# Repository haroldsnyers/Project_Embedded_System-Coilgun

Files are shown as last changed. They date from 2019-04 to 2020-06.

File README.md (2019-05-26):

# Project_Embedded_System-Coilgun
## Introduction
This Coilgun project is a project under the car of the ECAM.

The purpose of this project was to make a school laboratory experience which could be actionned remotely from the student's home. It was demanded to use atleast 2 of 3 following modules: 
- arduino
- Beagle Bone Black
- PIC

We choose the arduino and the BBB. The arduino will be connected the coilgun electronic circuit, to a proximity sensor and a bouton. The type of connection we chooses to connect the arduino to the BBB is through uart and finally by MQTT we choose to connect the BBB with the Node-RED interface. 

## SETUP
### arduino
One of the things we wanted to measure was the speed of the projectile. To do that we took a proximity sensor and a push button. In the arduino code, a first variable is activated when the projectile passes the sensor and a counter starts, then only if that variable is activated, it listens to the pin connected to the button and when pushed (projectile has reached target), counter stops and this time the value is send through uart to the BBB. The pins of the arduino connected to the buttons can be read in the code, same as the RX and TX port for the uart connection, pin 10 and 11 respectively.
When everything is setup upload the arduino file into your arduino board.
### Beagle Bone black
The arduino is connected via uart to the UART1 of the BBB, p9.24 and p9.26, TX and RX respectively. One more cable is needed to connect the arduino and BBB on the same GND. 
When everything is setup, you will need to upload the files read and write into the BBB (easy way : use filezila, connect `sftp://<IpAdress>`, username and password).
Open then 2 bash terminals and connect to your BBB on each of them. When connected on each of those terminals to the BBB, enter the following commands
```
config-pin p9.24 uart
config-pin p9.26 uart
stty -F /dev/ttyO1 sane
```
After that just run the two python scripts running the following commands : 
```
python readuart_Arduin-BBB-Dash.py
```
and 
```
python writeUart_Dash-BBB-Arduino.py
```
The readuart script retrieves data send by the arduino in the form of a string, this string is then decomposed by means of a letter describing which data it is and in function of that publish the value in right topic generated by the Node-RED interface. 
The write uart retrieves data from a topic of the Node-RED interface he is subscribed to and send this data through uart to the arduino board.
### Node-RED
You need to start from your command prompt node-red and go to the following pair `<IP:port>` in your browser `localhost:1880`
After that you can download the flow for the Node-RED dashboard in JSON form. This can be done by clicking on the dropdown in the upper right corner and choosing import from clipboard. After that you can go to the dashboard by going to `http://localhost:1880/ui`.
You should arrive to a dashboard looking like this : 

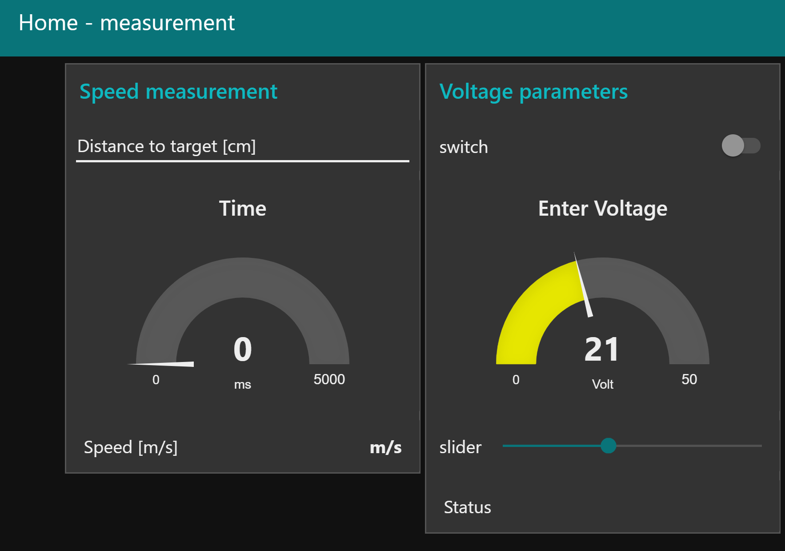
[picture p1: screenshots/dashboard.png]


The Speed bloc works with the following nodes :
- **_input text node_** to input the distance between the coilgun and the target
- **_gauge node_** to display the time it took to reach the target
- **_text node_** to display the speed of the projectile
- **_mqtt IN node_** to subscribe to the topic sensor/time

The speed will only be displayed if the distance has been given and the time has been pusblished. This can be done with the following function :

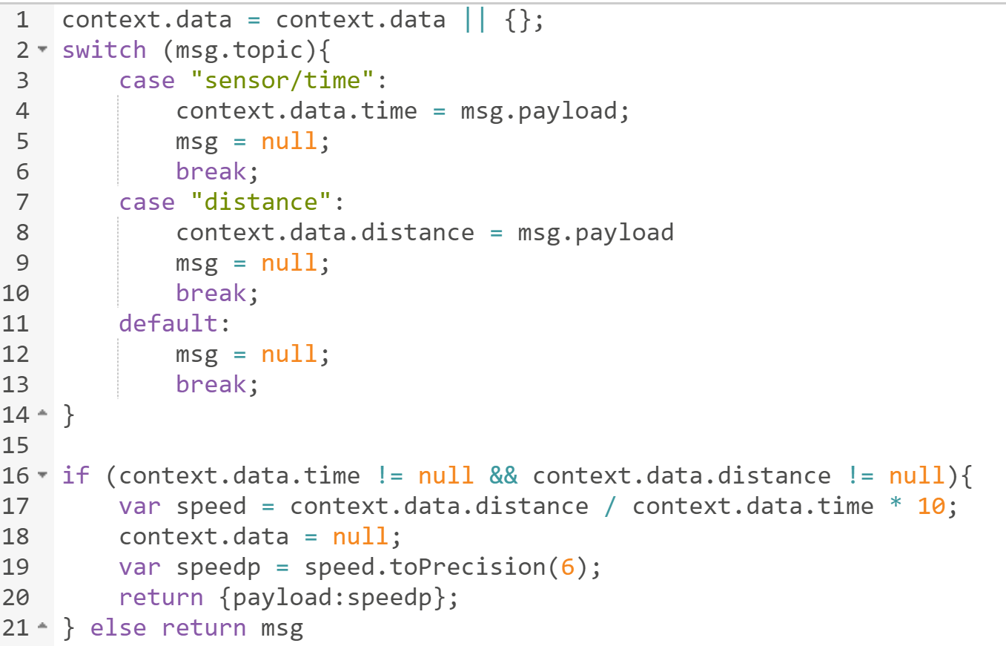
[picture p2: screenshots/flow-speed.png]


The voltage bloc works with the following nodes :
- **_switch node_** to enable the launch 
- **_gauge node_** to display the voltage selected with the slider
- **_slider node_** to select to voltage to launch the projectile
- **_text node_** to display the status of the launch
- **_mqtt IN node_** to subscribe to the topic sensor/conf
- **_mqtt OUT node_** to publish to the topic sensor/test

The voltage will be send to the arduino if the switch is ON and the slider has been moved after that with the following questions :

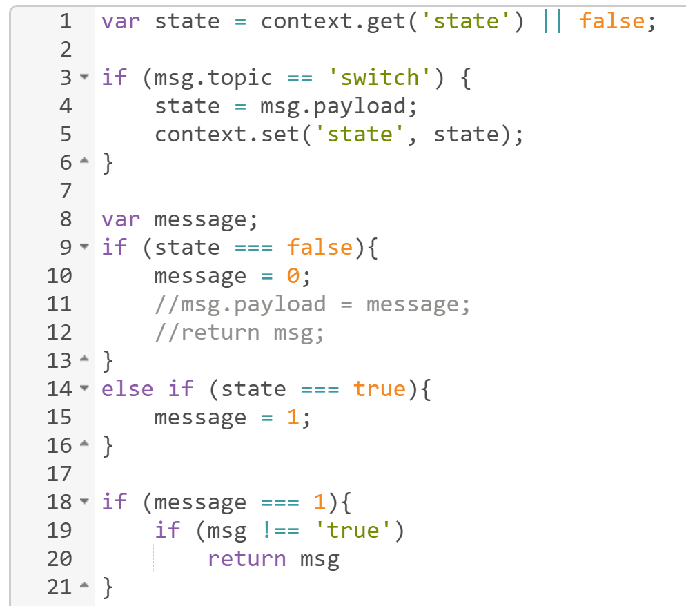
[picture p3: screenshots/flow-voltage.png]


The status mqtt IN sends a status message about the launch if the voltage has been send properly to the arduino.

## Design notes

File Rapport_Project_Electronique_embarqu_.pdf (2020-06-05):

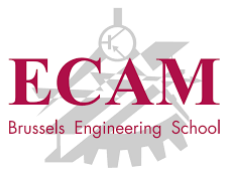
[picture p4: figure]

Projet Electronique Embarqué

# Canon de Gauss

Auteurs :
Harold Snyers 16243
Bernard Tourneur 16148
Christos Bournousouzis 16219

Professeurs :
Mr. Sébastien Combefis ´

Mr. Cédric Marchand

Un canon électromagnétique contrôlé à distance

depuis un tableau de bord

Année académique 2018-2019

## Contents

Contents | i
1 Canon de Gauss | 1
A Appendix | 8

Page - i

## Canon de Gauss

## 1.1 Introduction

L’objectif du projet est d’implémenter une expérience de laboratoire de niveau secondaire,

contrôlable à distance depuis un ordinateur. L’utilisateur doit pouvoir déclencher l’expérience,

et récupérer les éventuelles données à collecter, le tout depuis un panneau de bord (ou

”dashboard”) sur son ordinateur.

Nous avons choisi comme sujet d’expérience l’électromagnétisme et le rendement énergétique.

L’expérience consiste à mesurer l’énergie cinétique d’un projectile lancé par un canon de

Gauss (ou canon électromagnétique), à la comparer avec l’énergie électrique consommée

par le système, pour en déterminer le rendement énergétique.

## 1.2 Développement électronique

### 1.2.1 Fonctionnement du canon

Un canon de Gauss consiste en un bobinage cylindrique creux, le projectile placé en

son centre, auquel on applique un pic de courant important. Ce dernier va générer une

variation de flux magnétique, créant une force magnétomotrice maximale au centre de

la bobine et lançant ainsi le projectile. Plusieurs facteurs affectent la valeur de la force

magnétomotrice générée; la bobine en elle même, son impédance, le nombre de tours de

fils, etc; mais également le courant électrique qui la traverse, et la quantité d’énergie

disponible.

Ainsi, pour pouvoir libérer un maximum de courant le plus vite possible, nous avons choisi

d’accumuler les charges dans des condensateurs (à capacité relativement grande).

Pour charger les condensateurs (placés parallèlement à la bobine), le circuit doit être ou-

vert derrière ceux-ci, et ils doivent être mis sous tension. Une fois les condensateurs pleins

(lorsque leur tension est plus ou moins égale à la tension de charge), on peut fermer le

circuit (à l’aide d’un relais électromécanique); la bobine se comportera alors comme un

court-circuit (ou une résistance très faible) et les condensateurs se déchargeront brusque-

ment, provoquant un pic de courant important dans la bobine.

Canon de Gauss

Il est important que le relais ne soit fermé qu’un bref instant, pour que l’impulsion

soit momentanée; si elle dure trop longtemps, la force magnétomotrice provoquera une

décélération du projectile.

### 1.2.2 Schémas

Tous les schémas du système se trouvent en annexe; les références vers ceux-ci pointent

donc vers la fin de ce document.

Voici le détail des composants du schéma général (Figure A.1):

- Condensateur x 6
- Résistance x 6
- Diode x 1
- Relais x 1
- Bobine x 1

La source de tension est contrôlable à distance; elle n’a pas été intégrée dans notre pro-

totype mais est nécessaire pour un contrôle complet du système à distance.

Analysons le schéma général par bloc fonctionnel.

a Charge des condensateurs

(Figure A.2)

Dans ce bloc, la résistance sert à limiter le courant de charge des condensateurs. Les condensateurs vont donc se charger jusqu’à la tension d’alimentation du système¹
, moins

la tension présente sur la diode (environ 0.7 V). Cette dernière sert à empêcher la décharge

des condensateurs lorsque la source est éteinte; sans elle, les condensateurs pourraient se

décharger au travers de la résistance.

b Décharge des condensateurs

(Figure A.3)

Pour fermer le circuit, un relais électromécanique est placé entre les condensateurs et la

bobine, faisant office d’interrupteur. L’entrée du relais, (qui commande l’électro-aimant

1Dans notre prototype, 50V

Canon de Gauss

activant la commutation) est connectée à une sortie de l’Arduino. Lorsque l’Arduino

envoie 5V, le relais est passant et le projectile lancé.

Comme mentionné précédemment, il faut que le relais soit fermé pendant un temps rela-

tivement court. Nous avons déterminé par essai-erreur que, sous 50V, un temps ”passant”

de 150 ms suffit.

Pour éviter que les condensateurs continuent de se charger lors du tir, nous avons choisi

d’éteindre la source de courant avant la mise à feu. Nous avons en effet constaté une

légère augmentation de performances dans ces circonstances. L’hypothèse retenue est que

le courant entrant dans les condensateurs limite le courant sortant, diminuant ainsi la

valeur totale de courant dans la bobine.

Pour avoir un grand gain de courant, nous avons décidés de mettre nos condensateurs en

parallèle.

Si nous faisons le calcul :
Avec Rtot ' 30 ohm, pour un condensateur on a : I = 50
30 = 1.67A

Itot = I*6 ' 10A, on aurait donc +/- 10A qui passerait dans notre bobine pour une

tension de 50V.

c Mesure de tension

(Figure A.4)

Pour mesurer la tension sur les condensateurs nous utilisons un diviseur de tension de rap-

port 10 (valeur expérimentale = 9.1314) car l’ADC de l’Arduino ne convertit pas une ten-

sion supérieur à 5V (si nous prenons la référence interne de l’Arduino bien évidemment).

Nous avons utilisé des résistances très grandes pour éviter d’avoir trop de perte de courant.

Nous prenons la mesure entre R2 et R3 et nous la connectons à une pin analogique de

l’Arduino.

d Mesure de courant

(Figure A.5)

Nous utilisons une résistance de puissance de 1 ohm comme résistance de shunt, pour

mesurer le courant passant dans la bobine.

U = R * I → U = 1 * I → U = I

La valeur de courant est donc directement donnée par la tension lue. Pour éviter d’endommager

l’ADC de l’Arduino en cas de pic de courant important, nous utilisons un diviseur de ten-

sion de rapport 3 (valeur expérimentale = 2.241).

Canon de Gauss

e Capteur de vitesse

(Figure A.6)

Pour déterminer la vitesse du projectile (qui sera utilisée pour trouver son énergie cinétique via E=(m∗v

2
2

), on procède en deux étapes : dans un premier temps, l’utilisateur entre la

distance entre le canon et la cible; ensuite, après le tir, le système détermine le temps de

parcours du projectile.

Pour calculer le temps de parcours, on place sous l’extrémité du canon un capteur in-

frarouge (connecté à l’Arduino), détectant le passage du projectile. L’instant de passage

du projectile est enregistré dans l’Arduino. Il s’agit d’un capteur digital, qui envoie un 1

logique lorsqu’il détecte un passage. Sur la cible est placé un bouton poussoir, connecté

également à l’Arduino. Lorsque le projectile atteint cette cible, il enfonce le bouton pous-

soir, qui envoie alors un 1 logique à l’Arduino.

Une simple différence tdépart - tarrivée permet de trouver le temps de parcours. La

vitesse sera calculée directement dans le dashboard.

### 1.2.3 Améliorations possibles

La diode pourrait être remplacée par un relais commandé via l’Arduino. Dans ce cas,

nous n’aurions plus besoin d’une source commandée mais d’une simple source qui restera

constamment branchée, l’Arduino contrôlant quand ouvrir le circuit et donc quand arrêter

la charge des condensateurs.

Pour optimiser la puissance du canon, il est recommandé de prendre une bobine avec un

noyau ferromagnétique.

Au niveau de la lecture de la tension sur les condensateurs et de la lecture du courant,

plusieurs choix s’offrent à nous; soit des résistances beaucoup plus précises pour le diviseur,

soit utiliser un ADC externe permettant de lire des tensions plus importantes.

Pour le capteur de vitesse, il faudrait remplacer le bouton poussoir. En effet, l’énergie

du projectile est insuffisante pour l’enfoncer. Ce problème pourrait être résolu soit en

utilisant un bouton plus sensible, soit en appliquant plus de tensions à la bobine, et donc

en fournissant plus d’énergie au projectile.

Le capteur de mouvements pose également problème; il ne détecte pas systématiquement

le passage du projectile. Idéalement, il faudrait mieux le positionner, en le fixant au

canon, et en s’assurant que le projectile passe systématiquement au dessus du capteur.

Canon de Gauss

## 1.3 Développement télématique

### 1.3.1 Choix des protocoles

Nous avons choisi le protocole UART pour la communication BBB-Arduino car :

- La librairie Serial Arduino implémente déjà ce protocole, est simple à utiliser et

fiable.

- La BBB et l’Arduino sont les seuls présents sur le bus; il n’y a aucun esclave donc

pas de relation maitre-esclave ni d’adressage nécessaire.

- La communication se fait dans les deux sens systématiquement, quand la BBB envoie

un msg elle doit recevoir une réponse, il est donc intéressant d’utiliser un protocole

full duplex.

Aucun protocole n’est utilisé pour les capteurs, qui envoient de simple signaux logiques

si nécessaire.

### 1.3.2 Configuration Arduino

Le code est disponible dans l’appendice section A.2.1.

Comme précisé, nous implémentons la communication UART à l’aide de la librairie Serial;

nous commençons par créer le bus mySerial et choisissons les pins utilisées.

S’en suit l’initialisation des variables et des pins. Dans le void setup, le bus Serial est

démarré et les pins les pins uart ou autres composants sont configurées.

Dans le void loop, il y a deux parties. Une partie permet de lire ce que l’Arduino reçoit

sur le Serial. Ici, elle attend de recevoir la valeur de la tension à appliquer afin d’activer

le premier transistor de puissance qui laissera donc passer la tension requise et donc de

charger les capacités. Quand le tension est atteinte, le transistor est coupé. L’autre

transistor est alors activé afin d’envoyer le courant sur la bobine.

Le bloc suivant permet de vérifier que la valeur de tension a bien été envoyée.

Enfin, le temps de parcours est calculé en testant d’abord si le projectile a survolé le

capteur de mouvement, ensuite s’il a enfoncé le bouton; à chaque évènement, il enregistre

le temps de passage, et fini par calculer une différence de temps qu’il peut envoyer à la

BBB.

Canon de Gauss

### 1.3.3 Configuration Beagle Bone Black

Pour lancer l’écoute et l’envoi des données entre la BeagleBone et l’Arduino nous avons

2 programmes, un pour l’écoute (readuart Arduin-BBB-Dash.py) et l’autre pour l’envoi

(writeUart Dash-BBB-Arduino.py). Ces 2 programmes vont permettre non seulement à

la BeagleBone de communiquer avec l’Arduino en UART mais également de communiquer

avec le dashboard via MQTT. Nous avons choisi d’écrire ces programmes en python pour ses avantages de clarté et de lisibilité, et parce que la librairie UART utilisée²
intègre des

fonctions C dans le code python, permettant des performances quasi équivalentes à un

code C, pour la communication.

La première chose à faire est de choisir sur quel port UART se connecter, puis le port de

la connexion MQTT, généralement le port 1883.

Les codes sont disponibles dans l’Appendice section A.2.2.

readuart Arduin-BBB-Dash.py

La BeagleBone attend de recevoir quelque chose de l’arduino et enregistre le contenu reçu

s’il y a des données disponible sur le Serial. Ensuite, il déchiffre les données reçues (chaque

information transmise en UART est identifiée par un caractère, permettant à la BBB de

différencier les valeurs reçues de l’Arduino) et en fonction, publier les valeurs obtenues

sur les topics respectifs. Les données reprises sur le Serial de l’Arduino sont en format

string, donc avant de les publier, les données numériques sont converties en int.

writeUart Dash-BBB-Arduino.py

La BBB attend de recevoir une valeur sur le topic sur lequel elle est abonnée et, lorsqu’une

valeur est disponible, envoie cette même valeur sur le Serial de l’Arduino.

### 1.3.4 Configuration DashBoard

Le dashboard présente l’interface utilisateur (Figure A.7). Il a été configuré à l’aide de

l’outil de programmation Node-RED.

Les données entrantes arrivent par 4 topics MQTT : sensor/time, sensor/current, sensor/-

voltageIn et sensor/conf. Le dashboard est composé de plusieurs parties. Il y a 4 com-

partiment, le premier affiche la mesure de la vitesse, le deuxième s’occupe d’envoyer les

paramètre de tension et affiche la tension réellement appliquée. Les 2 derniers sont respon-

sables d’afficher la mesure de courant et les la calcul de l’énergie cinétique et électrique.

2Adafruit BBIO.UART

Canon de Gauss

Le flux du dashboard se divise en deux parties.

La première partie (figure A.8), est composée d’un slider pour choisir la tension à appli-

quer, d’une gauge qui affiche la tension choisie et finalement un switch qui va permettre

d’activer l’envoi de la tension sur le topic sensor/voltage. Le topic entrant sensor/conf

affiche le status de l’envoi de la tension dans bloc texte.

La deuxième partie (figure A.9), est composée de 3 données entrantes par MQTT. Chacune

des valeurs de ces topics est affichée dans leur bloc texte respectif. Ensuite un bloc

”inputtext” permettra à l’utilisateur d’entrer la distance entre le canon et la cible.

Une fonction est chargée de récupérer les valeurs des différents topic MQTT et la distance

entrée, d’envoyer les valeurs de tension et de courant aux afficheurs respectifs, puis de

calculer les valeurs de vitesse, énergie cinétique et électrique, et enfin le rendement. Le

code est disponible dans l’annexe à la section A.2.3.

En pratique, la tension choisie n’influence pas le système dans notre prototype; la tension

de charge des condensateurs sera toujours égale à la tension d’alimentation, puisque nous

ne disposons pas d’alimentation contrôlable électriquement, et n’avons pas implémenté

le relais de contrôle mentionné plus tôt. L’envoi de la tension aura donc pour seul

conséquence la mise à feu immédiate du canon de Gauss.

## 1.4 Conclusion

Le projet est fonctionnel, bien qu’il ne soit qu’un prototype et qu’il y ait encore beau-

coup de place pour des améliorations. Certaines parties de l’expérience doivent encore

être simulées manuellement (il faut appuyer sur le bouton poussoir, cfr section 1.2.3:

améliorations possibles).

Le projet a été très instructif à plusieurs niveaux; comme premier projet où nous avons

conçu et designé un circuit électronique, nous avons beaucoup appris de nos erreurs et

développé des raisonnements de conceptions. De plus, le projet a permis d’approfondir

notre compréhension des protocoles MQTT et UART.

Nous sommes donc globalement satisfaits du déroulement du projet.

## Appendix

## A.1 Schéma

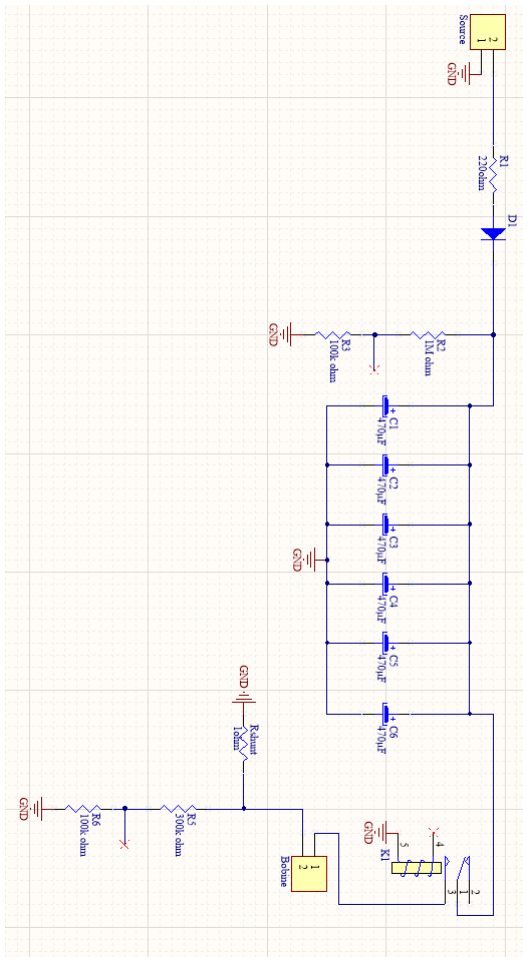
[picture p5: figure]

Figure A.1: Schéma Global

Appendix A. Appendix

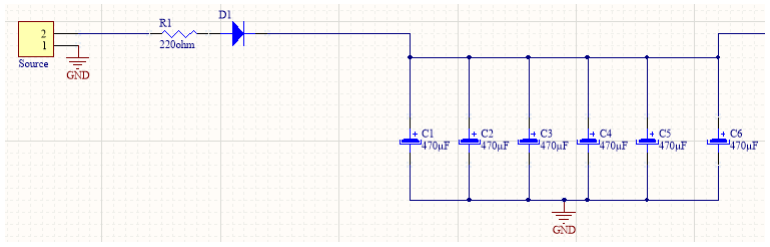
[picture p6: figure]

Figure A.2: Schéma de Charge

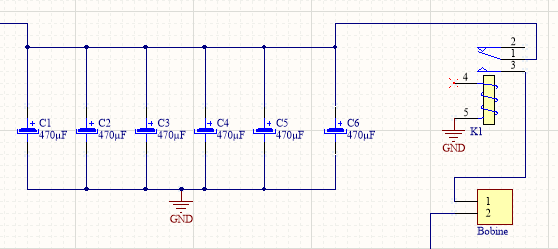
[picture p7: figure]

Figure A.3: Schéma de Décharge

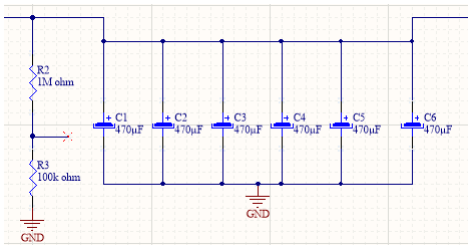
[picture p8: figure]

Figure A.4: Schéma du Voltmètre

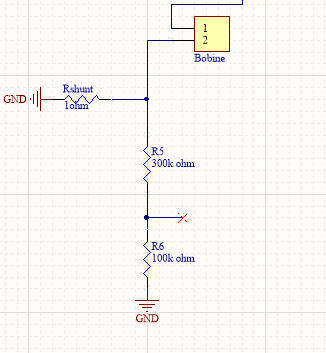
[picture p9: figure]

Figure A.5: Schéma de l’Ampèremètre

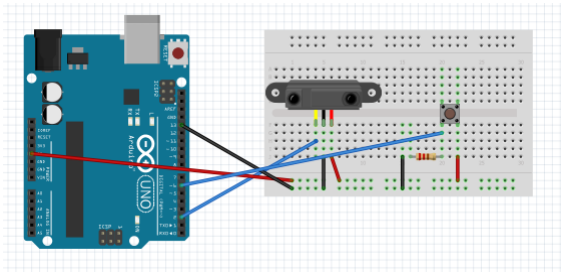
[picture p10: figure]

Figure A.6: Schéma du Capteur de Passage

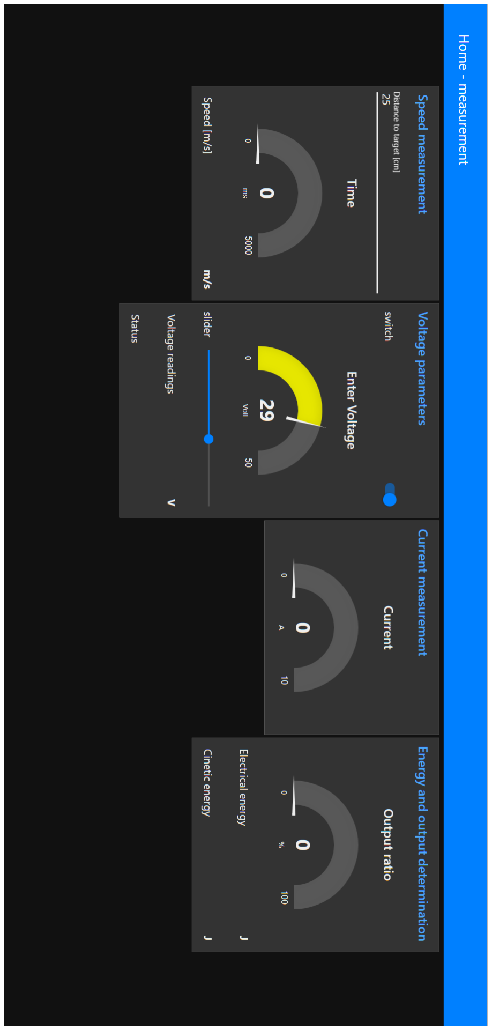
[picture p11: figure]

Figure A.7: Interface utilisateur

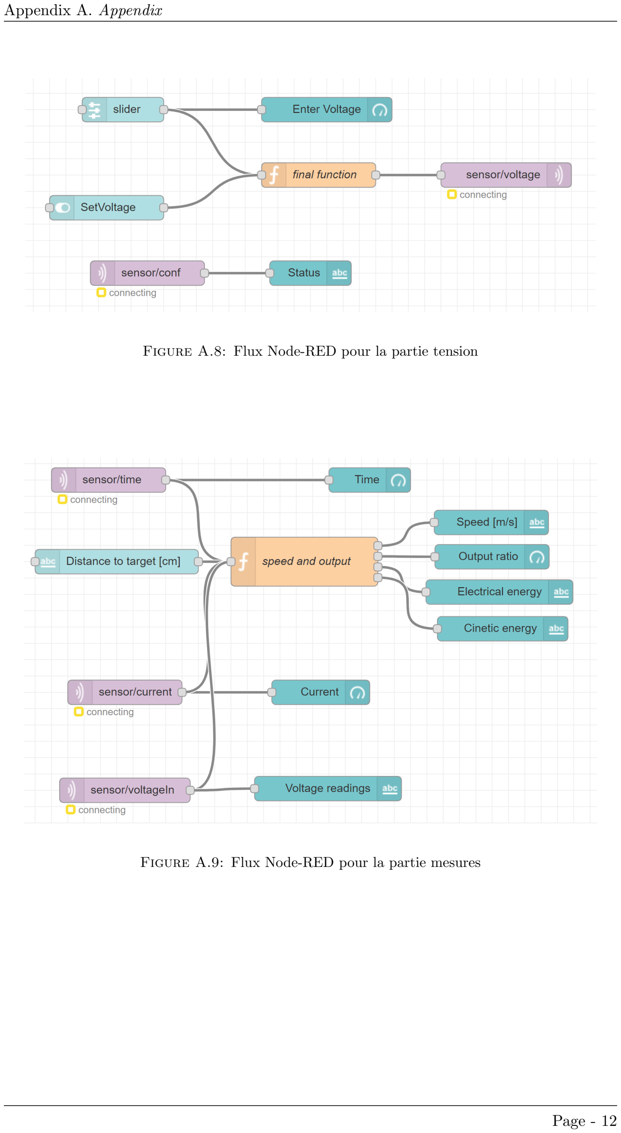
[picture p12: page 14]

Figure A.8: Flux Node-RED pour la partie tension

Figure A.9: Flux Node-RED pour la partie mesures

A.2 | Code
A.2.1 | Arduino
1 | #include <SoftwareSerial.h>
2 | #include <Wire.h>

3
4 SoftwareSerial mySerial = SoftwareSerial(10,11);

5
6 | // set pin numbers
7 | const char IRCaptor = 2;
8 | const int buttonPin = 6;

9
10 | // initialisation variables
11 | long passageTime;
12 | long impactTime;
13 | float deltaT = 0;
14 | int buttonState = 0;
15 | int departed = 0;
16 | int voltageValue = 0;
17 | int test = 0;
18 | String confirmation = "";
19 | int verif = 0;
20 | float current;
21 | float inputVoltage;

22
23 | void setup()
24 | {
25 | Serial.begin(9600);

26
27 | // uart configuration with BBB
28 | pinMode(10,INPUT);
29 | pinMode(11,OUTPUT);
30 | mySerial.begin(9600);

31
32 | // configuration of captors and transistors
33 | pinMode(IRCaptor, INPUT);
34 | pinMode(buttonPin, INPUT);

35

36 }

37
38 | void loop()
39 | {
40 | // BBB to arduino

41

42
43 | if(mySerial.available() > 0)
44 | {
45 | String storedData = "";
46 | // reading data into char array

while(mySerial.available())

{

char inChar = mySerial.read();

storedData += inChar;

}

voltageValue = storedData.toInt();

delay(500);

// changing verification status to now that a value has been read

verif = 1;
// only if voltage value chosen is high enough, activate relays

if (voltageValue > 14){

Serial.print("helloboys\n");

digitalWrite(7, HIGH);

delay(150);

digitalWrite(7, LOW);

confirmation = "launched";

}

}

// to detect when the projectile has been launched

if (digitalRead(IRCaptor) == LOW and departed == 0)

{

passageTime = millis();

Serial.print("detected\n");

departed = 1;

}

// read the state of the pushbutton value:

buttonState = digitalRead(buttonPin);

// check if the pushbutton is pressed.

// thus projectile has reached target

// if it is, the buttonState is HIGH:

if (buttonState == HIGH && departed == 1) {

Serial.print("Impact\n");

impactTime = millis();

// Time projectile to target = time(buttonPushed) - time(IRcaptor)

deltaT = (impactTime - passageTime );

Serial.print(deltaT);

Serial.print("\n");

departed = 0;

}

// sending of the speed of object and output

if (deltaT != 0){

int speed1 = deltaT;
int voltageIn = (analogRead(A1)*(5.0/1023.0)*9.1314);

int current = (analogRead(A0)*(5.0/1023.0)*2.241);

String voltInS = String(voltageIn);

String currentS = String(current);

String speed1S = String(speed1);

99
100 | Serial.print("S" + speed1S);
101 | // sends data with 'char' to enable recognition of the data
102 | mySerial.println("S" + speed1S + "C" + currentS + "V" + voltInS);
103 | Serial.print("\n");
104 | Serial.print("Test confirmed\n");
105 | deltaT = 0;
106 | test = 5;
107 | }

108
109 | // sends status of the launching
110 | if (verif != 0){
111 | String conf = "not launched";
112 | if (confirmation != ""){
113 | conf = confirmation;
114 | }
115 | mySerial.println("l" + conf);
116 | verif = 0;
117 | }
118 | }

A.2.2 | BeagleBone
a | readuart Arduin-BBB-Dash.py

import Adafruit_BBIO.UART as UART

import serial

import paho.mqtt.publish as publish

import paho.mqtt.client as mqtt

# selecting the uart on which you want to communicate UART.setup("UART1")

disp = serial.Serial(port = "/dev/ttyO1", baudrate = 9600)

disp.close()

disp.open()

while True:
client = mqtt.Client()

client.connect("localhost", 1883, 60)

# initializing lists for string separation chars = []

charsSpeed = []

charsVoltIn = []

charsCurrent = []

charsConf = []

case1 = 0

case2 = 0

if disp.isOpen():

print "I'm reading\n"

line = disp.readline()

print line
# getting all data retrieved from uart connection in same list

for i in line:
chars.append(i)

size1 = len(chars)

i = 0

while i < size1:

# getting speed data

if chars[i] == 'S':

case1 = 1 #means start of frame

i = i + 1
while chars[i] != 'C':

charsSpeed.append(chars[i])

i = i + 1

# getting voltage data

if chars[i] == 'C':

i = i + 1
while chars[i] != 'V':

charsCurrent.append(chars[i])

i = i + 1

# getting voltage data

if chars[i] == 'V':

i = i + 1
while chars[i] != '\r':

charsVoltIn.append(chars[i])

i = i + 1

# getting confirmation data

if chars[i] == "l":

case2 = 1 #means end of frame =>status received

i = i + 1
while chars[i] != "\r":

charsConf.append(chars[i])

i = i + 1

i = size1

# publish the different datasets on the right topics through MQTT

if case1 == 1:
valueSpeed = int("".join(map(str, charsSpeed)))

valueVoltIn = int("".join(map(str, charsVoltIn)))

valueCurrent = int("".join(map(str, charsCurrent)))

publish.single("sensor/time", valueSpeed, hostname="localhost")

publish.single("sensor/voltageIn", valueVoltIn, hostname="localhost")

publish.single("sensor/current", valueCurrent, hostname="localhost")

if case2 == 1:
valueConf = ''.join(charsConf)

print 'publish'
publish.single("sensor/conf", valueConf, hostname="localhost")

disp.close()

b writeUart Dash-BBB-Arduino.py

import Adafruit_BBIO.UART as UART

import serial

import paho.mqtt.client as mqtt

import paho.mqtt.subscribe as subscribe

client = mqtt.Client()

# selecting the uart on which you want to communicate UART.setup("UART1")

disp = serial.Serial (port = "/dev/ttyO1", baudrate=9600)

disp.close()

disp.open()

while True:
if disp.isOpen():

print "Serial is Open\n"

client.connect("localhost", 1883, 60)

# reading the data coming from the topic it is subscribed to msg = subscribe.simple("sensor/voltage", hostname="localhost")

print("%s %s" % (msg.topic, msg.payload))

msg = msg.payload
print(msg)

# sending only the voltage value if msg != "true":

disp.write(msg)

disp.write("\n")

print "Sorry!!! You not able to do communicate with device" disp.close()

A.2.3 Node-RED

Fonction dans le flux Node-RED responsable de la récupération des mesures

context.data = context.data || {};

var speedp;
var cinetic_energy = 0;

var electrical_energy = 0;

var output = 0;

var voltage = 0;
switch (msg.topic){

case "sensor/time":

context.data.time = msg.payload;

msg = null;

break;
case "distance":

context.data.distance = msg.payload

msg = null;

break;
case "sensor/voltage":

voltage = msg.payload;

msg = null;

break;
case "sensor/current":

context.data.currentVal = msg.payload;

msg = null;

break;
default:

msg = null;

break;

}

if (context.data.time !== null && context.data.distance !== null){

var speed = context.data.distance / context.data.time * 10;

context.data = null;
speedp = speed.toPrecision(6);

cinetic_energy = 0.01*(speedp*speedp)/2; //mass = 10g

}

/*we consider power value as a peak

forming a linear function (first degree) of slope P/delta Time (dt) which can be integrated to find energy = E =(P/dt)* (dt)²/2 = (P*dt)/2

for one side of the peak
=> E = P*dt for both sides of the peak*/

if ((voltage !== null)&&(context.data.currentVal !== null)){

var power = voltage * context.data.currentVal; //peak of power

electrical_energy = power*0.05; //dt = 50ms for a 100 ms peak

}

if ((cinetic_energy !== 0)&&(electrical_energy !== 0)){

output = cinetic_energy/electrical_energy;

}

48 | return[{payload:speedp}, {payload:output}, {payload:electrical_energy},
49 | {payload:cinetic_energy}];

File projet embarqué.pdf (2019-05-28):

# Projet embarqué

Réglages :
- Réglage de tension => arrêter le chargement de la capa à la tension voulue

Mesurer :
- tension sur les condensateurs,
- vitesse du clou => mesure du temps (t0 = temps d’éjection du clou, t1 = temps d’impact (capteur de vibration) => distance fixe),
- mesure ampérage en entrée du système => comparer énergie cinétique et énergie électrique => rendement.
- Capteur infrarouge pour détecter passage

Consignes:

1. une description de votre expérience
L’objectif de l’expérience est d’analyser le rendement énergétique d’un canon magnétique (coilgun). Pour ce faire, on détermine l’énergie cinétique d’un projectile (on place un obstacle à une distance d du canon, et on détermine le temps de parcours à l’aide du capteur de vibration, placé sur l’obstacle), et on la compare avec la consommation électrique du circuit (résistance de shunt et ADC pour le courant et la tension).
On utilise un capteur infrarouge pour détecter le passage du projectile à l’éjection du canon.
2. une illustration de l'ensemble de la chaîne
a. capteur/actionneur
i. ADC arduino
ii. | Capteur de vibration
iii. | Capteur infrarouge
iv. | Rshunt + tension (ADC) = courant en entrée
v. transistors de puissance = actionneur (décharge les condensateurs
| dans la bobine)
b. données manipulées/mesurées
i. charge des capacités
ii. | courant en entrée
iii. | courant dans la bobine
iv. | mesure du temps de déplacement
c. communication utilisée pour remonter cette donnée
i. I²C (capteurs-Arduino)
ii. USB ? (Arduino-BBB)

d. illustration du dashboard utilisateur
i. En cours d’initialisation de la conception (tenez vous prêt à vous tenir prêt)
3. une liste du matériel nécessaire
a. Condensateurs grande capacité (1 mF ou plus)
b. Bobine
c. Arduino
d. BeagleBone Black
e. Capteur de vibration
f. Capteur infrarouge (capteur de passage)
g. Transistors de puissance
h. Résistances

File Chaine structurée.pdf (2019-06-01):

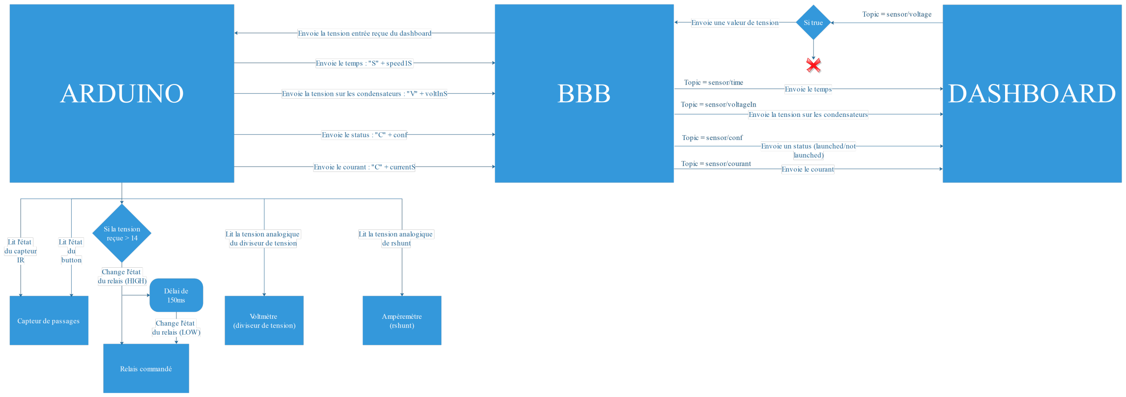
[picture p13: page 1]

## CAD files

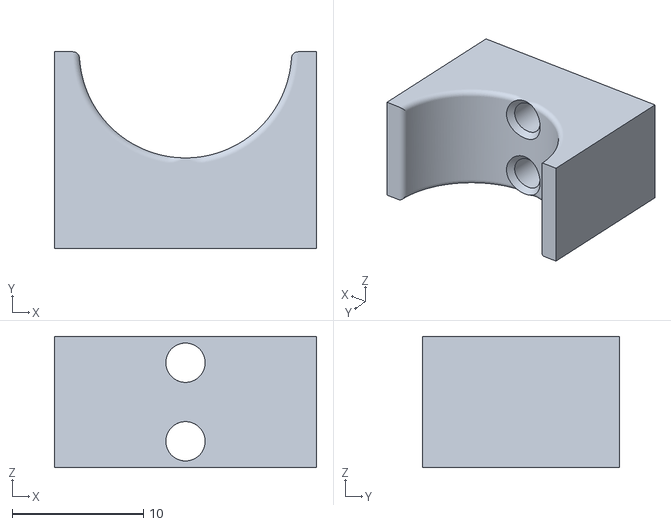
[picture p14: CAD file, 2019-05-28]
Support_bobine.stl
20.0 x 15.0 x 10.0

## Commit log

2019-05-27 edit codes for voltage readings on the dashboard
2019-05-28 Adding the PCB
    [Copy-of-PCB1.pcbdoc, PCB_Project1.PrjPCB, PcbLib1.PcbLib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]
2019-05-31 uart send voltage and current
2019-05-31 add current MQTT topic
2019-06-01 Add Structured Chain
2019-06-01 Add the analog read for the current et voltage
2019-06-01 Change the schematic
